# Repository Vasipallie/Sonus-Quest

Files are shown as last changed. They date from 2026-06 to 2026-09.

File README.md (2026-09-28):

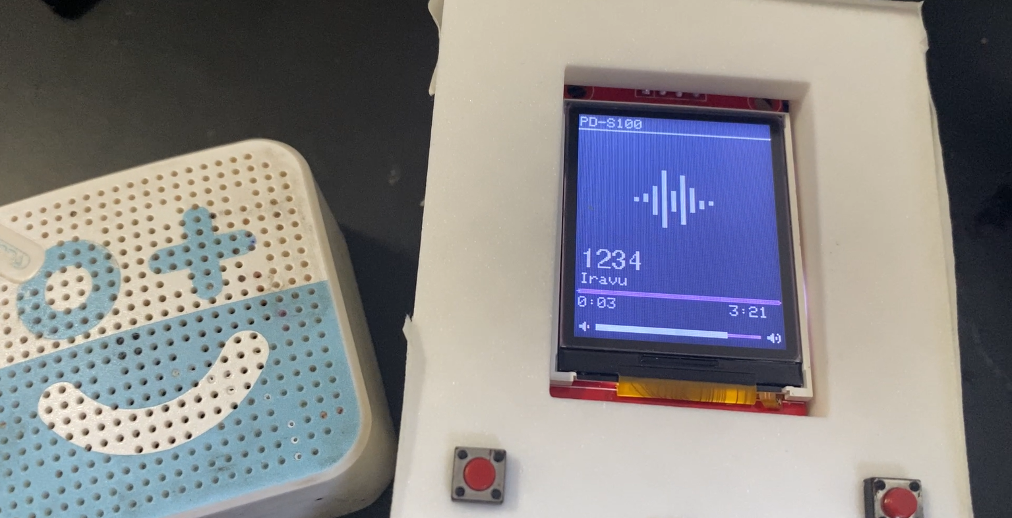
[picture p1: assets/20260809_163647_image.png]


# Sonus Quest

Sonus Quest is a Zune inspired opernsource music player based off of the ESP-32. It features audio playback via blueooth classic to bluetooth audio sinks (headphones, speakers, audio outputs with bluetooth functionality). The Sonus Quest comes with a companion application, Sonus Connect which allows you to upload songs directly onto an SD Card by converting music files into a format that can be recognised and played by your Sonus Quest.

View the demo here: [https://cdn.hackclub.com/019fe5ae-d175-72be-af3d-9535461abcc2/IMG_1770.MOV](https://cdn.hackclub.com/019fe5ae-d175-72be-af3d-9535461abcc2/IMG_1770.MOV)

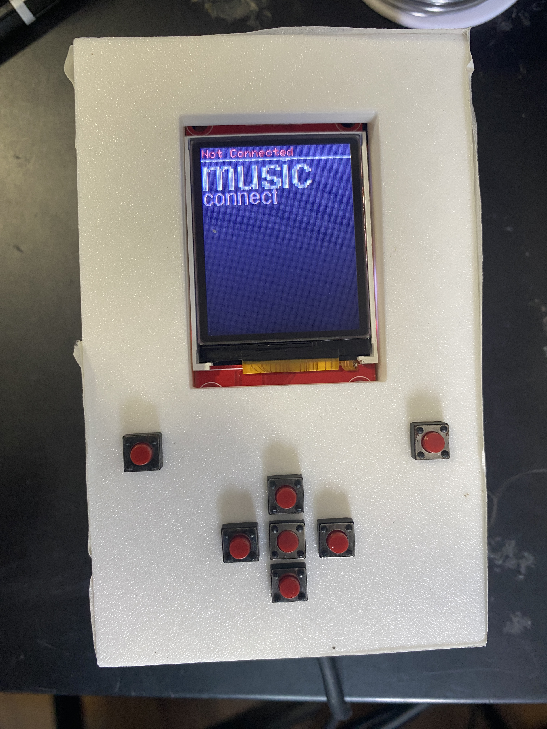
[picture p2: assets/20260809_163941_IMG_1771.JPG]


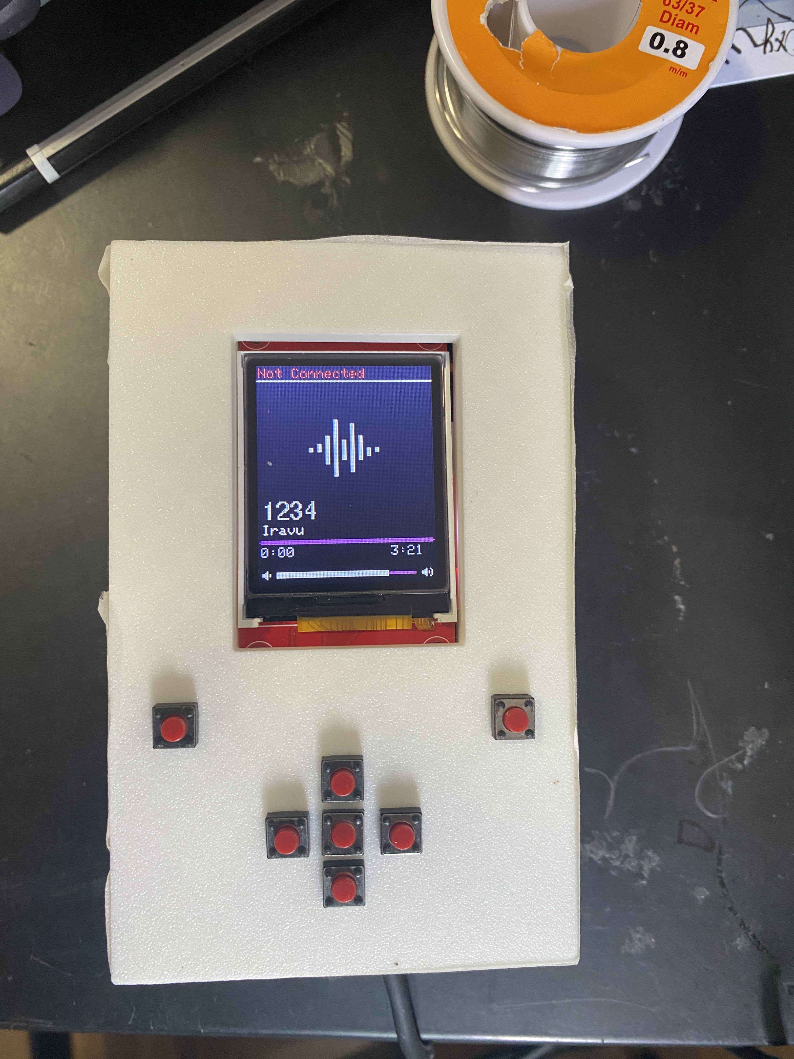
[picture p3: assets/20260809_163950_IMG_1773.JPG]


## Bill of Materials

This is the Bill of Materials incase you want to build your own Sonus
BOM.csv included in the repo for extra clarity

| Item | Description | Qty | Individual Cost | Total Cost | Vendor |
| --- | --- | --: | ---: | ---: | --- |
| ESP32-WROOM 32 | Microcontroller for the player | 1 | $3.44 | $3.44 | AliExpress |
| 1.8' LCD Screen | Shows the UI and helpful text  | 1 | $3.38 | $3.38 | AliExpress |
| Buttons (pack of 20) | Helps navigate the UI | 1 | $0.42 | $0.42 | AliExpress |
| SD Card | Storage for music files | 1 | $17.03 | $17.03 | Amazon |
| **TOTAL** | | | | **$24.27** | |

## Sonus Quest Case

Please visit the Sonus Quest Case folder in this repository, it contains the following

* STEP Files
* Stl Files
* For MACONDO, please visit the "Macondo STEP with electronics" to see the STEP file with electronics

You can also visit the onshape link: [OnShape Project](https://cad.onshape.com/documents/1512152095b2c0e2a477a4dd/w/cfa0c0da778d6d525583c585/e/f113794b6145e289ac0c9052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)

## Wiring Diagram

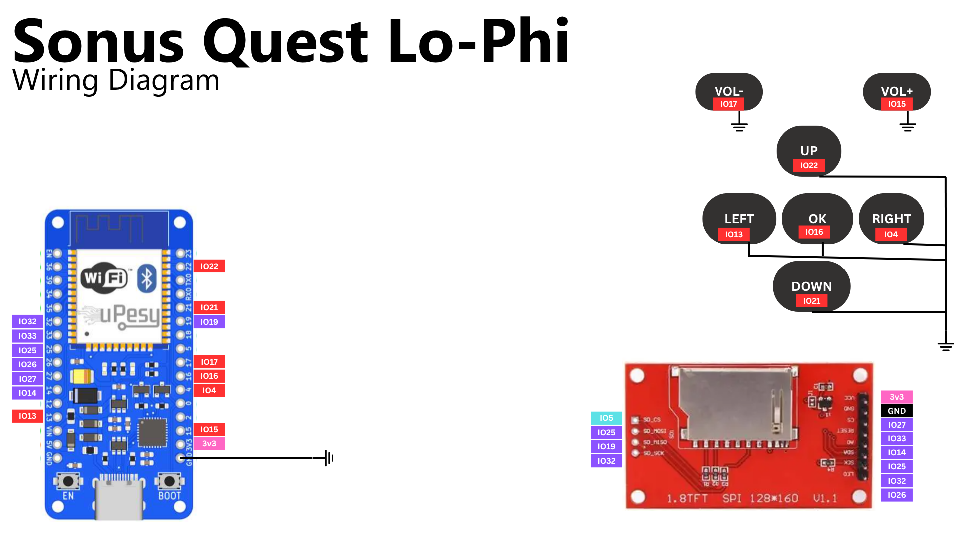
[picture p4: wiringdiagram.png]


## Sonus Connect

Sonus Connect allows you to upload your music files to your sonus quest by uploading it directly on your Sonus SD Card. Sonus Connect handles the following functionality that makes it easy to use.

1. Audio format conversion
2. Music Directory Addition
3. Intuitive User Interface

> Audio Format Conversion

The Sonus Quest by default uses a .raw audio format for easy decoding and audio playback with minimal memory usage, as opposed to popular audio formats such as mp3's this allows the Sonus Quest to handle an intuitive user interface instead of decoding mp3 data.

> Music Directory Addition

The Sonus Quest uses a custom music directory format using the file "sdir.txt", this contains vital data about songs so that there is faster bootup time on the Sonus Quest. An example of the sdir.txt file is as follows. A format for how the sdir.txt file is generated is also included in the example

````text
1-Unknown Title=Unknown Artist+test.raw>3:06;

indexnumber-Song Title=Artist Name+Filename>Duration;
```
````

### Screenshots from the App

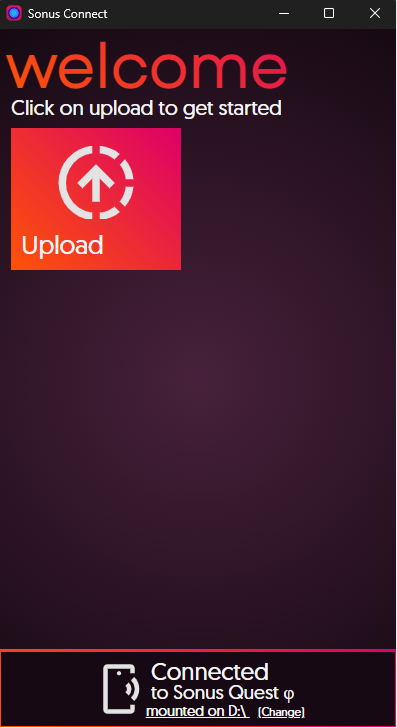
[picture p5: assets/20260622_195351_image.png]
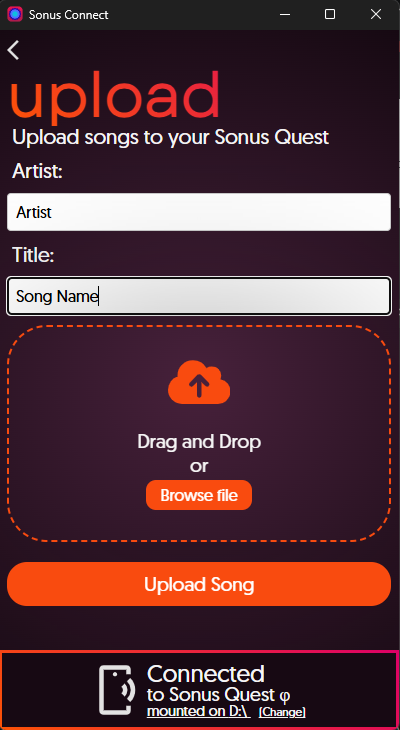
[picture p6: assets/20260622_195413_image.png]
 

# Sonus Quest

If you are planning to prototype your own version of the Sonus Quest, Here is a short guide that may help you.

> Button PIN Wiring

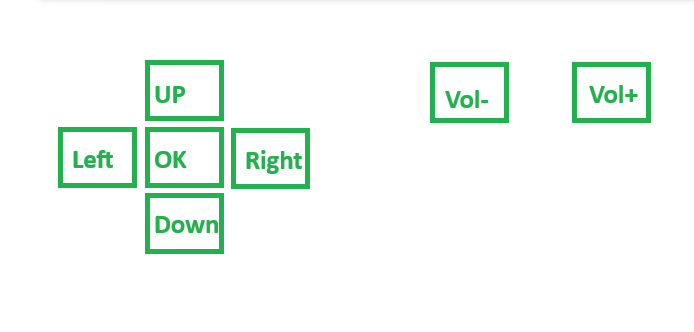
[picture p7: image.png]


LEFT: IO13

OK: IO16

RIGHT: IO4

UP: IO22

DOWN: IO21

VOL+: IO15

VOL-: IO17

> LCD PIN Wiring

TFT_CS:   27

TFT_RST:  33

TFT_DC:   26

TFT_MOSI: 25

TFT_SCLK: 32

TFT_BL:   14

I've personally used PlatformIO for uploading code onto the esp32, you may use any other software that lets you upload this code.

# Contribution

Contribution to the Sonus Quest repository is appreciated and encouraged, please fork this repository to make changes and create a pull request to get any changes reviewed and approved into the Sonus Quest Repository.

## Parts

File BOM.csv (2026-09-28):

Item | Description | Qty | Individual Cost | Total Cost | Vendor
ESP32-WROOM 32 | Microcontroller for the player | 1 | 3.44 | 3.44 | https://www.aliexpress.com/item/1005012522016246.html
1.8' LCD Screen | Shows the UI and helpful text | 1 | 3.38 | 3.38 | https://www.aliexpress.com/item/1005008042359126.html
Buttons (pack of 20) | Helps navigate the UI | 1 | 0.42 | 0.42 | https://www.aliexpress.com/item/1005006046180384.html
SD Card | Storage for music files | 1 | 17.03 | 17.03 | Amazon.com: SanDisk Ultra SDSQUNS-016G-GN3MN 16GB 80MB/s UHS-I Class 10 microSDHC Card : Electronics
TOTAL |  |  |  | 24.27

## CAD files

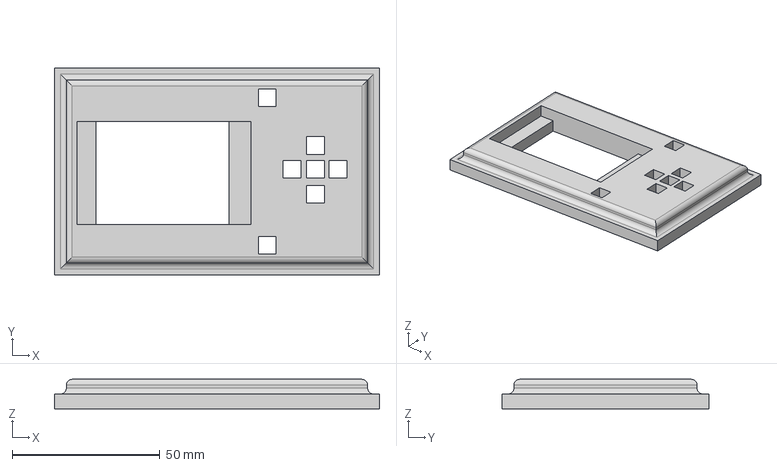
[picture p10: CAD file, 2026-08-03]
Sonus Quest Case/Case STEP files/Assembly 1 - Part 2.step
110.0 x 70.0 x 10.0 mm

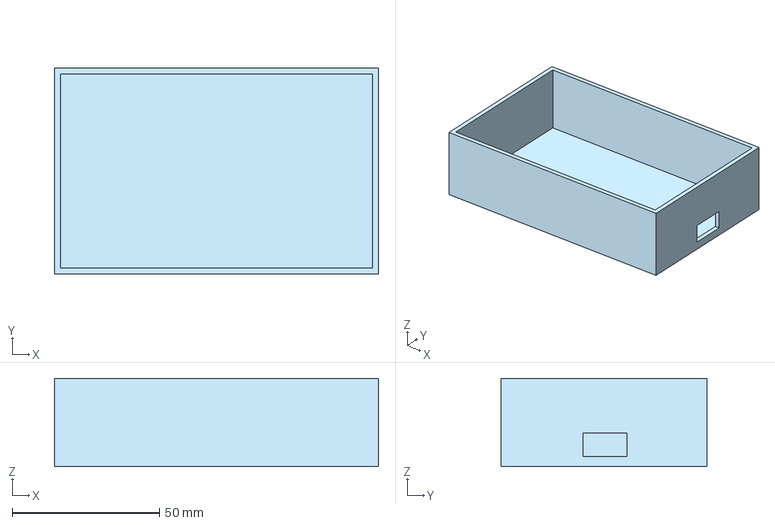
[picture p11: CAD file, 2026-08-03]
Sonus Quest Case/Case STEP files/Assembly 1 - Part 1.step
110.0 x 70.0 x 30.0 mm

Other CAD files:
Sonus Quest Case/Case Stl files/Assembly 1 - Part 1.stl
Sonus Quest Case/Case Stl files/Assembly 1 - Part 2.stl

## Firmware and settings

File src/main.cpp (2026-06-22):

//IMPORTS
#include <Arduino.h>
#include "BluetoothA2DPSource.h"
#include "BluetoothSerial.h"
#include "esp_gap_bt_api.h"
#include <SPI.h>
#include <SD.h>
#include <Adafruit_GFX.h>
#include <Adafruit_ST7735.h>
//PINS
#define TFT_CS   27
#define TFT_RST  33
#define TFT_DC   26
#define TFT_MOSI 25
#define TFT_SCLK 32
#define TFT_BL   14
const int SD_CS_PIN = 5;
#define MAX_DEVICES 13

//LOPAKA STUFF & Icons
String TARGET_SPEAKER = "NULL";
esp_bd_addr_t TARGET_ADDR = {0};
BluetoothA2DPSource a2dp_source;
BluetoothSerial SerialBT;
File                audio_file;
volatile bool       audio_sd_ready  = false;
volatile bool       audio_switch_pending = false;
volatile int        audio_pending_index  = -1;
int                 audio_playing_index  = -1;
bool                audio_paused         = false;

// BT connection state — set only from BT callbacks, read from main task
volatile bool       bt_connected         = false;
volatile bool       bt_status_changed    = false;  // triggers a status-bar redraw in loop()
volatile bool       pending_addr_save    = false;  // set when we learn the addr by name-match

volatile float      volume_gain          = 0.5f;
volatile int        current_volume       = 8;
const int           MAX_VOLUME           = 10;
const int           MIN_VOLUME           = 0;


struct AudioDevice {
  String  name;
  String  address;
};

AudioDevice foundDevices[MAX_DEVICES];
int selectedIndex = 0;
String deviceNames[MAX_DEVICES];
int deviceCount = 0;

String screenname ="";
/* 
ALL SCREEN NAMES
- "HOMEM"
- "HOMEC"
- "MUSILIST"
- "PLAYING"
- "CONNECT"
*/

// Returns the top-bar text: speaker name when connected, "not connected" otherwise
inline String getStatusText() {
  return bt_connected ? TARGET_SPEAKER : String("Not Connected");
}

static const int RECONNECT_INTERVAL = 0.5;   
class LopakaST7735 : public Adafruit_ST7735 {
public:
  using Adafruit_ST7735::Adafruit_ST7735;

  void setFreeFont(const GFXfont* f) { setFont(f); }

  int16_t drawString(const char* text, int16_t x, int16_t y) {
    int16_t x1, y1;
    uint16_t w, h;
    getTextBounds(text, 0, 0, &x1, &y1, &w, &h);
    setCursor(x, y - y1);
    print(text);
    return static_cast<int16_t>(w);
  }

  int16_t drawString(const String& text, int16_t x, int16_t y) {
    return drawString(text.c_str(), x, y);
  }
};
LopakaST7735 tft(TFT_CS, TFT_DC, TFT_MOSI, TFT_SCLK, TFT_RST);
const uint8_t FreeSerifBoldItalic9pt7bBitmaps[] PROGMEM = {
    0x0C, 0x31, 0xC6, 0x18, 0x41, 0x08, 0x20, 0x0E, 0x38, 0xE0, 0xCF, 0x38,
    0xA2, 0x88, 0x02, 0x40, 0xC8, 0x13, 0x06, 0x43, 0xFC, 0x32, 0x06, 0x40,
    0x98, 0x7F, 0x84, 0xC0, 0x90, 0x32, 0x04, 0xC0, 0x01, 0x01, 0xF0, 0x4B,
    0x99, 0x33, 0x24, 0x78, 0x07, 0x80, 0x38, 0x0B, 0x89, 0x31, 0x26, 0x64,
    0xC7, 0x30, 0x3C, 0x04, 0x00, 0x38, 0x41, 0x9F, 0x06, 0x48, 0x31, 0x60,
    0xCD, 0x03, 0x2C, 0x07, 0x27, 0x81, 0x39, 0x05, 0xC4, 0x26, 0x10, 0x98,
    0x84, 0x66, 0x10, 0xE0, 0x03, 0x80, 0x22, 0x03, 0x10, 0x19, 0x00, 0xF0,
    0x0F, 0x3C, 0xF8, 0xCC, 0xC4, 0xE7, 0x47, 0x3E, 0x38, 0xE1, 0xE7, 0x97,
    0xCF, 0x00, 0xFA, 0x80, 0x08, 0x88, 0x84, 0x62, 0x10, 0x84, 0x21, 0x08,
    0x41, 0x00, 0x20, 0x84, 0x10, 0x84, 0x21, 0x08, 0xC6, 0x23, 0x11, 0x00,
    0x18, 0x18, 0xD6, 0x38, 0x18, 0xF7, 0x18, 0x18, 0x08, 0x04, 0x02, 0x01,
    0x0F, 0xF8, 0x40, 0x20, 0x10, 0x08, 0x00, 0x6D, 0x95, 0x00, 0xFF, 0xC0,
    0xFF, 0x80, 0x06, 0x0C, 0x30, 0x60, 0x83, 0x04, 0x18, 0x20, 0xC1, 0x06,
    0x00, 0x0F, 0x0C, 0x8C, 0x6E, 0x37, 0x1B, 0x1F, 0x8F, 0xC7, 0xC7, 0x63,
    0xB1, 0x89, 0x83, 0x80, 0x06, 0x1E, 0x0E, 0x0E, 0x0C, 0x0C, 0x1C, 0x18,
    0x18, 0x18, 0x38, 0x38, 0xFC, 0x1F, 0x13, 0xD0, 0xE0, 0x70, 0x38, 0x38,
    0x18, 0x18, 0x18, 0x08, 0x08, 0x4F, 0xCF, 0xE0, 0x1F, 0x11, 0xC0, 0xE0,
    0x60, 0xC1, 0xF0, 0x38, 0x0C, 0x06, 0x03, 0x01, 0x19, 0x8F, 0x00, 0x00,
    0x80, 0xC0, 0xE1, 0xE0, 0xB0, 0x98, 0x9C, 0x8C, 0xFF, 0x07, 0x03, 0x01,
    0x80, 0x0F, 0x88, 0x08, 0x07, 0x83, 0xE0, 0x78, 0x1C, 0x06, 0x03, 0x01,
    0x80, 0x9C, 0x87, 0x80, 0x03, 0x87, 0x07, 0x07, 0x07, 0x03, 0xE3, 0x99,
    0xCC, 0xC6, 0x63, 0x33, 0x89, 0x87, 0x80, 0x3F, 0xBF, 0x90, 0x80, 0xC0,
    0x40, 0x60, 0x20, 0x30, 0x30, 0x10, 0x18, 0x08, 0x00, 0x1E, 0x13, 0x31,
    0x31, 0x3A, 0x1C, 0x1C, 0x6E, 0xC6, 0xC6, 0xC6, 0x44, 0x38, 0x0E, 0x1C,
    0x8C, 0x6C, 0x36, 0x3B, 0x1D, 0x8E, 0x7E, 0x0E, 0x07, 0x07, 0x0E, 0x0C,
    0x00, 0x39, 0xCE, 0x00, 0x03, 0x9C, 0xE0, 0x39, 0xCE, 0x00, 0x01, 0x8C,
    0x22, 0x20, 0x00, 0x01, 0xC3, 0xC7, 0x8E, 0x06, 0x01, 0xE0, 0x3C, 0x07,
    0x80, 0x40, 0xFF, 0x80, 0x00, 0x00, 0x0F, 0xF8, 0x00, 0x60, 0x1E, 0x03,
    0xC0, 0x78, 0x1C, 0x3C, 0x78, 0xF0, 0x40, 0x00, 0x1C, 0x27, 0x37, 0x07,
    0x0E, 0x1C, 0x30, 0x60, 0x40, 0x00, 0xE0, 0xE0, 0xE0, 0x0F, 0x80, 0xC3,
    0x08, 0x04, 0xC3, 0x3C, 0x24, 0xE2, 0x27, 0x33, 0x39, 0x11, 0xC9, 0x93,
    0x77, 0x18, 0x00, 0x70, 0x40, 0xFC, 0x00, 0x00, 0x80, 0x18, 0x01, 0x80,
    0x38, 0x05, 0x80, 0x5C, 0x09, 0xC1, 0x1C, 0x1F, 0xC2, 0x0C, 0x20, 0xC4,
    0x0E, 0xF3, 0xF0, 0x3F, 0xE0, 0xC7, 0x0C, 0x71, 0xC7, 0x1C, 0xE1, 0xF0,
    0x39, 0xC3, 0x8E, 0x38, 0xE3, 0x0E, 0x71, 0xE7, 0x1C, 0xFF, 0x00, 0x07,
    0xD1, 0xC7, 0x38, 0x27, 0x02, 0x70, 0x0F, 0x00, 0xE0, 0x0E, 0x00, 0xE0,
    0x0E, 0x00, 0x60, 0x87, 0x18, 0x1E, 0x00, 0x3F, 0xE0, 0x30, 0xE0, 0xC1,
    0x87, 0x07, 0x1C, 0x1C, 0x60, 0x73, 0x81, 0xCE, 0x07, 0x38, 0x38, 0xC0,
    0xE7, 0x07, 0x1C, 0x78, 0xFF, 0x80, 0x1F, 0xF8, 0x61, 0xC3, 0x04, 0x38,
    0x81, 0xCC, 0x0F, 0xE0, 0xE2, 0x07, 0x10, 0x38, 0x81, 0x81, 0x1C, 0x18,
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
const GFXglyph FreeSerifBoldItalic9pt7bGlyphs[] PROGMEM = {
    {0, 0, 0, 5, 0, 1},         // 0x20 ' '
    {0, 6, 13, 7, 1, -11},      // 0x21 '!'
    {10, 6, 5, 10, 3, -11},     // 0x22 '"'
    {14, 11, 13, 9, -1, -12},   // 0x23 '#'
    {32, 11, 15, 9, -1, -12},   // 0x24 '$'
    {53, 14, 13, 15, 1, -11},   // 0x25 '%'
    {76, 13, 13, 14, 0, -11},   // 0x26 '&'
    {98, 2, 5, 5, 3, -11},      // 0x27 '''
    {100, 5, 16, 6, 1, -11},    // 0x28 '('
    {110, 5, 16, 6, -1, -11},   // 0x29 ')'
    {120, 8, 8, 9, 1, -11},     // 0x2A '*'
    {128, 9, 9, 10, 0, -8},     // 0x2B '+'
    {139, 3, 6, 5, -1, -2},     // 0x2C ','
    {142, 5, 2, 6, 0, -4},      // 0x2D '-'
    {144, 3, 3, 4, 0, -1},      // 0x2E '.'
    {146, 7, 12, 6, 0, -11},    // 0x2F '/'
    {157, 9, 13, 9, 0, -11},    // 0x30 '0'
    {172, 8, 13, 9, 0, -11},    // 0x31 '1'
    {185, 9, 13, 9, 0, -11},    // 0x32 '2'
    {200, 9, 13, 9, 0, -11},    // 0x33 '3'
    {215, 9, 12, 9, 0, -11},    // 0x34 '4'
    {229, 9, 13, 9, 0, -11},    // 0x35 '5'
    {244, 9, 13, 9, 1, -11},    // 0x36 '6'
    {259, 9, 12, 9, 1, -11},    // 0x37 '7'
    {273, 8, 13, 9, 0, -11},    // 0x38 '8'
    {286, 9, 13, 9, 0, -11},    // 0x39 '9'
    {301, 5, 9, 5, 0, -7},      // 0x3A ':'
    {307, 5, 11, 5, 0, -7},     // 0x3B ';'
    {314, 9, 10, 10, 1, -9},    // 0x3C '<'
    {326, 9, 5, 10, 1, -6},     // 0x3D '='
    {332, 9, 10, 10, 1, -9},    // 0x3E '>'
    {344, 8, 13, 9, 1, -11},    // 0x3F '?'
    {357, 13, 13, 15, 1, -12},  // 0x40 '@'
    {379, 12, 13, 13, 0, -11},  // 0x41 'A'
    {399, 12, 13, 12, 0, -11},  // 0x42 'B'
    {419, 12, 13, 11, 1, -11},  // 0x43 'C'
    {439, 14, 13, 13, 0, -11},  // 0x44 'D'
    {462, 13, 13, 11, 0, -11},  // 0x45 'E'
    {484, 13, 13, 11, 0, -11},  // 0x46 'F'
    {506, 12, 13, 13, 1, -11},  // 0x47 'G'
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
const GFXfont FreeSerifBoldItalic9pt7b PROGMEM = {
    (uint8_t *)FreeSerifBoldItalic9pt7bBitmaps,
    (GFXglyph *)FreeSerifBoldItalic9pt7bGlyphs, 0x20, 0x7E, 22};
const uint8_t FreeSans9pt7bBitmaps[] PROGMEM = {
    0xFF, 0xFF, 0xF8, 0xC0, 0xDE, 0xF7, 0x20, 0x09, 0x86, 0x41, 0x91, 0xFF,
    0x13, 0x04, 0xC3, 0x20, 0xC8, 0xFF, 0x89, 0x82, 0x61, 0x90, 0x10, 0x1F,
    0x14, 0xDA, 0x3D, 0x1E, 0x83, 0x40, 0x78, 0x17, 0x08, 0xF4, 0x7A, 0x35,
    0x33, 0xF0, 0x40, 0x20, 0x38, 0x10, 0xEC, 0x20, 0xC6, 0x20, 0xC6, 0x40,
    0xC6, 0x40, 0x6C, 0x80, 0x39, 0x00, 0x01, 0x3C, 0x02, 0x77, 0x02, 0x63,
    0x04, 0x63, 0x04, 0x77, 0x08, 0x3C, 0x0E, 0x06, 0x60, 0xCC, 0x19, 0x81,
    0xE0, 0x18, 0x0F, 0x03, 0x36, 0xC2, 0xD8, 0x73, 0x06, 0x31, 0xE3, 0xC4,
    0xFE, 0x13, 0x26, 0x6C, 0xCC, 0xCC, 0xC4, 0x66, 0x23, 0x10, 0x8C, 0x46,
    0x63, 0x33, 0x33, 0x32, 0x66, 0x4C, 0x80, 0x25, 0x7E, 0xA5, 0x00, 0x30,
    0xC3, 0x3F, 0x30, 0xC3, 0x0C, 0xD6, 0xF0, 0xC0, 0x08, 0x44, 0x21, 0x10,
    0x84, 0x42, 0x11, 0x08, 0x00, 0x3C, 0x66, 0x42, 0xC3, 0xC3, 0xC3, 0xC3,
    0xC3, 0xC3, 0xC3, 0x42, 0x66, 0x3C, 0x11, 0x3F, 0x33, 0x33, 0x33, 0x33,
    0x30, 0x3E, 0x31, 0xB0, 0x78, 0x30, 0x18, 0x1C, 0x1C, 0x1C, 0x18, 0x18,
    0x10, 0x08, 0x07, 0xF8, 0x3C, 0x66, 0xC3, 0xC3, 0x03, 0x06, 0x1C, 0x07,
    0x03, 0xC3, 0xC3, 0x66, 0x3C, 0x0C, 0x18, 0x71, 0x62, 0xC9, 0xA3, 0x46,
    0xFE, 0x18, 0x30, 0x60, 0xC0, 0x7F, 0x20, 0x10, 0x08, 0x08, 0x07, 0xF3,
    0x8C, 0x03, 0x01, 0x80, 0xF0, 0x6C, 0x63, 0xE0, 0x1E, 0x31, 0x98, 0x78,
    0x0C, 0x06, 0xF3, 0x8D, 0x83, 0xC1, 0xE0, 0xD0, 0x6C, 0x63, 0xE0, 0xFF,
    0x03, 0x02, 0x06, 0x04, 0x0C, 0x08, 0x18, 0x18, 0x18, 0x10, 0x30, 0x30,
    0x3E, 0x31, 0xB0, 0x78, 0x3C, 0x1B, 0x18, 0xF8, 0xC6, 0xC1, 0xE0, 0xF0,
    0x6C, 0x63, 0xE0, 0x3C, 0x66, 0xC2, 0xC3, 0xC3, 0xC3, 0x67, 0x3B, 0x03,
    0x03, 0xC2, 0x66, 0x3C, 0xC0, 0x00, 0x30, 0xC0, 0x00, 0x00, 0x64, 0xA0,
    0x00, 0x81, 0xC7, 0x8E, 0x0C, 0x07, 0x80, 0x70, 0x0E, 0x01, 0x80, 0xFF,
    0x80, 0x00, 0x1F, 0xF0, 0x00, 0x70, 0x0E, 0x01, 0xC0, 0x18, 0x38, 0x71,
    0xC0, 0x80, 0x00, 0x3E, 0x31, 0xB0, 0x78, 0x30, 0x18, 0x18, 0x38, 0x18,
    0x18, 0x0C, 0x00, 0x00, 0x01, 0x80, 0x03, 0xF0, 0x06, 0x0E, 0x06, 0x01,
    0x86, 0x00, 0x66, 0x1D, 0xBB, 0x31, 0xCF, 0x18, 0xC7, 0x98, 0x63, 0xCC,
    0x31, 0xE6, 0x11, 0xB3, 0x99, 0xCC, 0xF7, 0x86, 0x00, 0x01, 0x80, 0x00,
    0x70, 0x40, 0x0F, 0xE0, 0x06, 0x00, 0xF0, 0x0F, 0x00, 0x90, 0x19, 0x81,
    0x98, 0x10, 0x83, 0x0C, 0x3F, 0xC2, 0x04, 0x60, 0x66, 0x06, 0xC0, 0x30,
    0xFF, 0x18, 0x33, 0x03, 0x60, 0x6C, 0x0D, 0x83, 0x3F, 0xC6, 0x06, 0xC0,
    0x78, 0x0F, 0x01, 0xE0, 0x6F, 0xF8, 0x1F, 0x86, 0x19, 0x81, 0xA0, 0x3C,
    0x01, 0x80, 0x30, 0x06, 0x00, 0xC0, 0x68, 0x0D, 0x83, 0x18, 0x61, 0xF0,
    0xFF, 0x18, 0x33, 0x03, 0x60, 0x3C, 0x07, 0x80, 0xF0, 0x1E, 0x03, 0xC0,
    0x78, 0x0F, 0x03, 0x60, 0xCF, 0xF0, 0xFF, 0xE0, 0x30, 0x18, 0x0C, 0x06,
    0x03, 0xFD, 0x80, 0xC0, 0x60, 0x30, 0x18, 0x0F, 0xF8, 0xFF, 0xC0, 0xC0,
    0xC0, 0xC0, 0xC0, 0xFE, 0xC0, 0xC0, 0xC0, 0xC0, 0xC0, 0xC0, 0x0F, 0x83,
    0x0E, 0x60, 0x66, 0x03, 0xC0, 0x0C, 0x00, 0xC1, 0xFC, 0x03, 0xC0, 0x36,
    0x03, 0x60, 0x73, 0x0F, 0x0F, 0x10, 0xC0, 0x78, 0x0F, 0x01, 0xE0, 0x3C,
    0x07, 0x80, 0xFF, 0xFE, 0x03, 0xC0, 0x78, 0x0F, 0x01, 0xE0, 0x3C, 0x06,
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
const GFXglyph FreeSans9pt7bGlyphs[] PROGMEM = {
    {0, 0, 0, 5, 0, 1},        // 0x20 ' '
    {0, 2, 13, 6, 2, -12},     // 0x21 '!'
    {4, 5, 4, 6, 1, -12},      // 0x22 '"'
    {7, 10, 12, 10, 0, -11},   // 0x23 '#'
    {22, 9, 16, 10, 1, -13},   // 0x24 '$'
    {40, 16, 13, 16, 1, -12},  // 0x25 '%'
    {66, 11, 13, 12, 1, -12},  // 0x26 '&'
    {84, 2, 4, 4, 1, -12},     // 0x27 '''
    {85, 4, 17, 6, 1, -12},    // 0x28 '('
    {94, 4, 17, 6, 1, -12},    // 0x29 ')'
    {103, 5, 5, 7, 1, -12},    // 0x2A '*'
    {107, 6, 8, 11, 3, -7},    // 0x2B '+'
    {113, 2, 4, 5, 2, 0},      // 0x2C ','
    {114, 4, 1, 6, 1, -4},     // 0x2D '-'
    {115, 2, 1, 5, 1, 0},      // 0x2E '.'
    {116, 5, 13, 5, 0, -12},   // 0x2F '/'
    {125, 8, 13, 10, 1, -12},  // 0x30 '0'
    {138, 4, 13, 10, 3, -12},  // 0x31 '1'
    {145, 9, 13, 10, 1, -12},  // 0x32 '2'
    {160, 8, 13, 10, 1, -12},  // 0x33 '3'
    {173, 7, 13, 10, 2, -12},  // 0x34 '4'
    {185, 9, 13, 10, 1, -12},  // 0x35 '5'
    {200, 9, 13, 10, 1, -12},  // 0x36 '6'
    {215, 8, 13, 10, 0, -12},  // 0x37 '7'
    {228, 9, 13, 10, 1, -12},  // 0x38 '8'
    {243, 8, 13, 10, 1, -12},  // 0x39 '9'
    {256, 2, 10, 5, 1, -9},    // 0x3A ':'
    {259, 3, 12, 5, 1, -8},    // 0x3B ';'
    {264, 9, 9, 11, 1, -8},    // 0x3C '<'
    {275, 9, 4, 11, 1, -5},    // 0x3D '='
    {280, 9, 9, 11, 1, -8},    // 0x3E '>'
    {291, 9, 13, 10, 1, -12},  // 0x3F '?'
    {306, 17, 16, 18, 1, -12}, // 0x40 '@'
    {340, 12, 13, 12, 0, -12}, // 0x41 'A'
    {360, 11, 13, 12, 1, -12}, // 0x42 'B'
    {378, 11, 13, 13, 1, -12}, // 0x43 'C'
    {396, 11, 13, 13, 1, -12}, // 0x44 'D'
    {414, 9, 13, 11, 1, -12},  // 0x45 'E'
    {429, 8, 13, 11, 1, -12},  // 0x46 'F'
    {442, 12, 13, 14, 1, -12}, // 0x47 'G'
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
const GFXfont FreeSans9pt7b PROGMEM = {(uint8_t *)FreeSans9pt7bBitmaps,
                                       (GFXglyph *)FreeSans9pt7bGlyphs, 0x20,
                                       0x7E, 22};
static const unsigned char PROGMEM image_Warning_bits[] = {0x00,0x03,0x00,0x00,0x00,0x07,0x80,0x00,0x00,0x0f,0xc0,0x00,0x00,0x0f,0xc0,0x00,0x00,0x1f,0xe0,0x00,0x00,0x3c,0xf0,0x00,0x00,0x3c,0xf0,0x00,0x00,0x7c,0xf8,0x00,0x00,0xfc,0xfc,0x00,0x00,0xfc,0xfc,0x00,0x01,0xfc,0xfe,0x00,0x03,0xfc,0xff,0x00,0x03,0xfc,0xff,0x00,0x07,0xfc,0xff,0x80,0x0f,0xfc,0xff,0xc0,0x0f,0xfc,0xff,0xc0,0x1f,0xfc,0xff,0xe0,0x3f,0xff,0xff,0xf0,0x3f,0xff,0xff,0xf0,0x7f,0xfc,0xff,0xf8,0xff,0xfc,0xff,0xfc,0xff,0xff,0xff,0xfc,0x7f,0xff,0xff,0xf8};
static const unsigned char PROGMEM image_music_sound_wave_bits[] = {0x00,0x00,0x00,0x00,0x00,0x00,0x00,0x00,0x00,0x00,0x00,0x00,0x00,0x00,0x00,0x00,0x00,0x00,0x00,0x00,0x00,0x00,0x00,0x38,0x00,0x00,0x00,0x00,0x00,0x00,0x38,0x00,0x00,0x00,0x00,0x00,0x00,0x38,0x00,0x00,0x00,0x00,0x00,0x00,0x38,0x03,0x80,0x00,0x00,0x00,0x00,0x38,0x03,0x80,0x00,0x00,0x00,0x00,0x38,0x03,0x80,0x00,0x00,0x00,0x00,0x38,0x03,0x80,0x00,0x00,0x00,0x00,0x38,0x03,0x80,0x00,0x00,0x00,0x00,0x38,0x03,0x80,0x00,0x00,0x00,0x00,0x38,0x03,0x80,0x00,0x00,0x00,0x00,0x38,0x03,0x80,0x00,0x00,0x00,0x00,0x38,0x03,0x80,0x00,0x00,0x00,0x0e,0x38,0x03,0x8e,0x00,0x00,0x00,0x0e,0x38,0x03,0x8e,0x00,0x00,0x00,0x0e,0x38,0x03,0x8e,0x00,0x00,0x00,0x0e,0x38,0xe3,0x8e,0x00,0x00,0x00,0x0e,0x38,0xe3,0x8e,0x00,0x00,0x00,0x0e,0x38,0xe3,0x8e,0x00,0x00,0x03,0x8e,0x38,0xe3,0x8e,0x00,0x00,0x03,0x8e,0x38,0xe3,0x8e,0x00,0x00,0x03,0x8e,0x38,0xe3,0x8e,0x00,0x00,0xe3,0x8e,0x38,0xe3,0x8e,0x38,0xe0,0xe3,0x8e,0x38,0xe3,0x8e,0x38,0xe0,0xe3,0x8e,0x38,0xe3,0x8e,0x38,0xe0,0x00,0x0e,0x38,0xe3,0x8e,0x38,0x00,0x00,0x0e,0x38,0xe3,0x8e,0x38,0x00,0x00,0x0e,0x38,0xe3,0x8e,0x38,0x00,0x00,0x0e,0x38,0xe3,0x8e,0x00,0x00,0x00,0x0e,0x38,0xe3,0x8e,0x00,0x00,0x00,0x0e,0x38,0xe3,0x8e,0x00,0x00,0x00,0x0e,0x38,0x03,0x80,0x00,0x00,0x00,0x0e,0x38,0x03,0x80,0x00,0x00,0x00,0x0e,0x38,0x03,0x80,0x00,0x00,0x00,0x00,0x38,0x03,0x80,0x00,0x00,0x00,0x00,0x38,0x03,0x80,0x00,0x00,0x00,0x00,0x38,0x03,0x80,0x00,0x00,0x00,0x00,0x38,0x03,0x80,0x00,0x00,0x00,0x00,0x38,0x03,0x80,0x00,0x00,0x00,0x00,0x38,0x03,0x80,0x00,0x00,0x00,0x00,0x38,0x00,0x00,0x00,0x00,0x00,0x00,0x38,0x00,0x00,0x00,0x00,0x00,0x00,0x38,0x00,0x00,0x00,0x00,0x00,0x00,0x00,0x00,0x00,0x00,0x00,0x00,0x00,0x00,0x00,0x00,0x00,0x00,0x00,0x00,0x00,0x00,0x00,0x00,0x00};
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
void loop() {
  update_playing_progress();

  if (bt_status_changed) {
    bt_status_changed = false;
    updateStatusBar();
  }
  if (pending_addr_save) {
    pending_addr_save = false;
    saveSpeaker(TARGET_SPEAKER, TARGET_ADDR);
  }

  if (audio_switch_pending) {
    audio_switch_pending = false;
    if (audio_pending_index >= 0 && audio_pending_index < songCount) {
      selectedSong = audio_pending_index;
      openAudioFile(audio_pending_index);
    }
  }

  static bool lastNext = HIGH;
  static bool lastBack = HIGH;
  static bool lastCONFIRM = HIGH;
  static bool lastUP = HIGH;
  static bool lastDOWN = HIGH;
  static bool lastRIGHT = HIGH;
  static bool lastLEFT = HIGH; 

  
  bool nowNext = digitalRead(BTN_NEXT);
  bool nowBack = digitalRead(BTN_BACK);
  bool nowCONFIRM = digitalRead(CONFIRM);
  bool nowUP = digitalRead(UP);
  bool nowDOWN = digitalRead(DOWN); 
  bool nowRIGHT = digitalRead(RIGHT);
  bool nowLEFT = digitalRead(LEFT);
 
   if (lastUP == HIGH && nowUP == LOW) {
    Serial.println("UP Pressed");
    volup();
    delay(150);
  }
    if (lastDOWN == HIGH && nowDOWN == LOW) {
      Serial.println("DOWN Pressed");
      voldown();
      delay(150);
    }
  if (lastNext == HIGH && nowNext == LOW) {
    Serial.println("NEXT Pressed");
    if (screenname == "HOMEM"){
      screenname = "HOMEC";
      homec();
    } else if (screenname == "MUSILIST"){
      if (songCount > 0 && selectedSong < songCount - 1) {
        selectedSong++;
        musiclist(false);
      }
    } else if (screenname == "CONNECT" && deviceCount > 0) {
      if (selectedIndex < deviceCount - 1) {
        selectedIndex++;
        int ypos[] = {29, 38, 47, 56, 65, 74, 83, 92, 101, 110, 119, 128, 137};
        tft.setFreeFont(NULL);
        tft.setTextSize(1);
        for (int i = 0; i < deviceCount; i++) {
          tft.setTextColor(i == selectedIndex ? 0xF419 : 0xFFFF);
          tft.drawString(foundDevices[i].name.c_str(), 3, ypos[i]);
        }
      }
    }
    delay(150);
  }
  if (lastBack == HIGH && nowBack == LOW) {
    Serial.println("BACK Pressed");
    if (screenname == "HOMEC"){
      screenname = "HOMEM";
      homem();
    } else if (screenname == "MUSILIST"){
      if (songCount > 0 && selectedSong > 0) {
        selectedSong--;
        musiclist(false);
      }
    } else if (screenname == "CONNECT" && deviceCount > 0) {
      if (selectedIndex > 0) {
        selectedIndex--;
        int ypos[] = {29, 38, 47, 56, 65, 74, 83, 92, 101, 110, 119, 128, 137};
        tft.setFreeFont(NULL);
        tft.setTextSize(1);
        for (int i = 0; i < deviceCount; i++) {
          tft.setTextColor(i == selectedIndex ? 0xF419 : 0xFFFF);
          tft.drawString(foundDevices[i].name.c_str(), 3, ypos[i]);
        }
      }
    } else if (screenname == "CONNECT") {
      screenname = "HOMEC";
      homec();
    }
    delay(150);
  }
  if (lastCONFIRM == HIGH && nowCONFIRM == LOW) {
    Serial.println("CONFIRM Pressed");
    if (screenname == "HOMEM"){
      screenname = "MUSILIST";
      musiclist();
    } else if (screenname == "PLAYING"){
        if (audio_file) {
          audio_paused = !audio_paused;
          audio_sd_ready = !audio_paused;
          Serial.println(audio_paused ? "[AUDIO] Paused" : "[AUDIO] Resumed");
        }
      } else if (screenname == "MUSILIST"){
      if (songCount > 0) {
        openAudioFile(selectedSong);
      }
    } else if (screenname == "HOMEC"){
      screenname = "CONNECT";
      connect();
    } else if (screenname == "CONNECT" && deviceCount > 0) {
      TARGET_SPEAKER = foundDevices[selectedIndex].name;
      Serial.printf("[BT] Connecting to: %s\n", TARGET_SPEAKER.c_str());

      tft.fillScreen(0x1042);
      tft.setFreeFont(&FreeSans9pt7b);
      tft.setTextColor(0xECFA);
      tft.setTextSize(2);
      tft.drawString("connect", 1, -3);
      tft.setFreeFont(NULL);
      tft.setTextSize(1);
      tft.setTextColor(0xFFFF);
      tft.drawString("Connecting to:", 10, 60);
      tft.drawString(TARGET_SPEAKER, 10, 74);

      saveSpeaker(TARGET_SPEAKER, TARGET_ADDR);

      if (a2dp_source.is_connected()) {
        a2dp_source.end(false);
        delay(300);
      } 

      esp_bt_gap_set_scan_mode(ESP_BT_NON_CONNECTABLE, ESP_BT_NON_DISCOVERABLE);

      int bondCount = esp_bt_gap_get_bond_device_num();
      if (bondCount > 0) {
        esp_bd_addr_t* bondList = new esp_bd_addr_t[bondCount];
        esp_bt_gap_get_bond_device_list(&bondCount, bondList);
        for (int i = 0; i < bondCount; i++) {
          esp_bt_gap_remove_bond_device(bondList[i]);
        }
        delete[] bondList;
        delay(200);
      }

      esp_bt_gap_set_scan_mode(ESP_BT_CONNECTABLE, ESP_BT_NON_DISCOVERABLE);

      sscanf(foundDevices[selectedIndex].address.c_str(),
             "%hhx:%hhx:%hhx:%hhx:%hhx:%hhx",
             &TARGET_ADDR[0], &TARGET_ADDR[1], &TARGET_ADDR[2],
             &TARGET_ADDR[3], &TARGET_ADDR[4], &TARGET_ADDR[5]);

      static const esp_bd_addr_t zeroAddr = {0};
      if (memcmp(TARGET_ADDR, zeroAddr, sizeof(esp_bd_addr_t)) != 0) {
        a2dp_source.set_auto_reconnect(TARGET_ADDR, 5);
      } else {
        a2dp_source.set_auto_reconnect(true, 5);
      }
      static char speakerBuf[64];
      TARGET_SPEAKER.toCharArray(speakerBuf, sizeof(speakerBuf));
      a2dp_source.start(speakerBuf);

      screenname = "HOMEM";
      homem();
    }
    delay(150);
  }
  if (lastRIGHT == HIGH && nowRIGHT == LOW) {
    Serial.println("RIGHT Pressed");
    if (screenname == "HOMEM"){
      screenname = "MUSILIST";
      musiclist();

    } else if (screenname == "HOMEC"){
      screenname = "CONNECT";
      connect();
    } else if (screenname == "MUSILIST"){
      if (songCount > 0) {
        openAudioFile(selectedSong);
      }
    } else if (screenname == "PLAYING"){
      if (songCount > 0 && selectedSong < songCount - 1) {
        selectedSong++;
        openAudioFile(selectedSong);
      }
    }
    delay(150);
  }
  if (lastLEFT == HIGH && nowLEFT == LOW) {
    Serial.println("LEFT Pressed");
    if (screenname == "MUSILIST"){
      screenname = "HOMEM";
      homem();
    } else if (screenname == "CONNECT"){
      screenname = "HOMEC";
      homec();
    } else if (screenname == "PLAYING"){
      if (songCount > 0 && selectedSong > 0) {
        selectedSong--;
        openAudioFile(selectedSong);
      }
    }
    delay(150);
  }
  
  static unsigned long leftPressStart = 0;
  if (lastLEFT == LOW && nowLEFT == LOW) {
    if (leftPressStart == 0) {
      leftPressStart = millis();
    } else if (millis() - leftPressStart > 2000) { 
      Serial.println("LEFT Long Pressed");
      
        if (audio_file) {
          audio_file.close();
          audio_sd_ready = false;
        }
      if (screenname == "PLAYING") {
        screenname = "MUSILIST";
        musiclist();
      }
      leftPressStart = 0; 
    }
  } else {
    leftPressStart = 0; 
  } 
  lastNext    = nowNext;
  lastBack    = nowBack;
  lastCONFIRM = nowCONFIRM;
  lastUP      = nowUP;   
  lastDOWN    = nowDOWN; 
  lastRIGHT = nowRIGHT;
  lastLEFT = nowLEFT; 

}

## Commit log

2026-06-20 sonus connect via tauri framework
2026-06-22 added navigation buttons, ready for release
2026-06-22 added left right buttons, fixed the duration and added new bar indicating duration of song similar to other audio players. also fixed a small name problem in tauri
    [main.cpp]
2026-06-22 changed code for bug issue in connect release, Added readme
    [main.cpp]
2026-07-06 added BOM
2026-07-11 wiring diagram added
2026-08-03 added case
    [Assembly 1 - Part 1.step, Assembly 1 - Part 1.stl, Assembly 1 - Part 2.step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]
2026-08-03 changes files to include a port for usb
    [Assembly 1 - Part 1.step, Assembly 1 - Part 1.stl, Assembly 1 - Part 2.step]
2026-08-07 added wiring diagram properly
2026-09-28 added demo link, bom changes to include total
    [BOM.csv]
